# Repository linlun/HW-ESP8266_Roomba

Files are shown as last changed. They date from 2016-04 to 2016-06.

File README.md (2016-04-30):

# HW-ESP8266_Roomba
Kicad schematics of a generic ESP8266 board with interfaces for OLED-display, rotary encoder, Roomba and DC/DC

Make shore that the latest kicad libraries are installed at: C:\Program Files\KiCad\share\kicad
Download from https://github.com/KiCad/kicad-library adn extract in the folder above if not.

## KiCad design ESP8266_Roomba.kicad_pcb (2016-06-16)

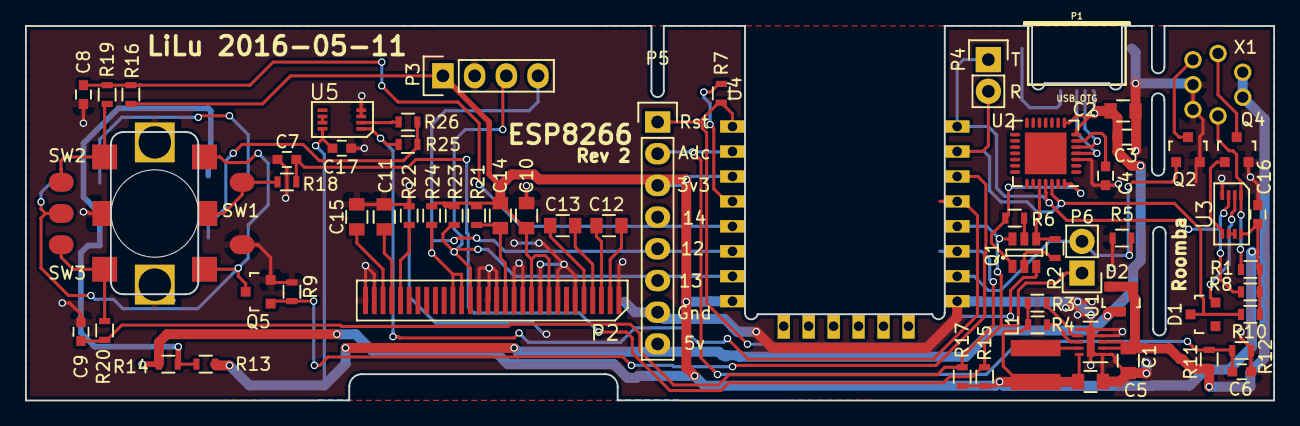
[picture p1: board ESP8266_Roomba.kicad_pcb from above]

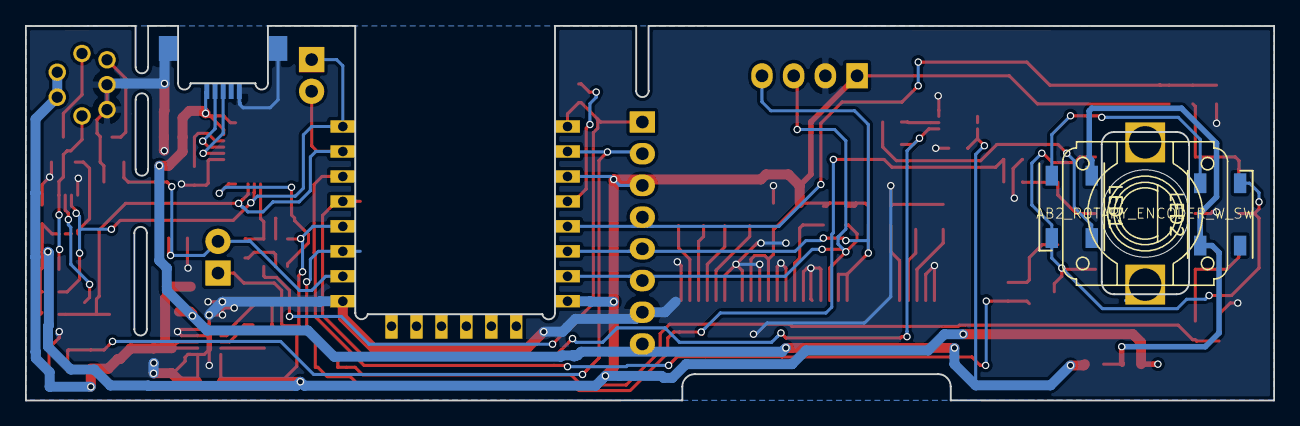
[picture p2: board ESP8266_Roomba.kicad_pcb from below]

Board: 2 copper layers, 100.0 x 30.0 mm, 68 parts (3 on the bottom side), 50 nets.

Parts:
C1, C11, C14, C15: 2u2; C_0805
C2, C10, C12, C13: 1u; C_0805
C3, C4, C6, C7, C8, C9, C16, C17: 100n; C_0603
C5: 22u; C_0805
D1, D2: MMBD717LT1G; SOT-23
L1: VLS4012ET-100M
LED1, LED2: WS2812B; LED_WS2812B-PLCC4
P1: USB_OTG; conn_usb_B_micro_smd-backside
P2: UG_62864
P3: CONN_01X04; Pin_Header_Straight_1x04
P4, P6: CONN_01X02; Pin_Header_Straight_1x02
P5: CONN_01X08; Pin_Header_Straight_1x08
Q1: DMC204010R; SOT-23-6
Q2, Q4, Q5: 2N7002; SOT-23
R1: 1M; R_0603
R2, R6, R7, R15, R16, R17, R21, R23, R24: 10k; R_0603
R3, R4, R5, R8, R9, R10: 100k; R_0603
R11: 470k; R_0603
R12: 18k; R_0603
R13, R14, R25, R26: 0R; R_0603
R18, R19, R20: 1k; R_0603
R22: 390k; R_0603
ROT_ENC1: AB2_ROTARY_ENCODER_W_SW; ROT_ENC_backside
SW1, SW2, SW3: SW_PUSH; switch3x6_smd
U1: TPS62177; DFN-10-1EP_2x3mm_Pitch0.5mm
U2: CP2102; QFN-28-1EP_5x5mm_Pitch0.5mm
U3, U5: 74LVC3G14; VSSOP-8
U4: ESP-12E; ESP-12E_SideMounted
X1: MINI_DIN_7; MiniDin-7

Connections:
+3V3: C5.1, C10.1, C14.1, C16.1, L1.2, P2.9, P2.11, P3.1, P5.3, R1.2, R3.1, R4.1, R8.1, R10.1, R14.1, R15.2, R16.2, R17.2, R21.2, R23.2, R24.2, U1.10, U3.8, U4.8
+12V: C1.1, D2.1, D2.2, R11.1, U1.2, U1.3, X1.1, X1.2
/5V: C2.1, C3.1, C17.1, D2.3, P1.1, P5.8, R13.2, U2.7, U2.8, U5.8
/ADC: C6.1, P5.2, R11.2, R12.1, U4.2
/DTR: Q1.1, R6.1, U2.28
/Enc_A: C9.1, R17.1, R20.2, U4.17
/Enc_B: C8.1, P5.4, R16.1, R19.2, U4.5
/LED: R25.2, U4.19, U5.1
/PowerOn: Q5.1, R9.2, U4.20
/RST: P5.1, Q1.3, R7.2, U4.1
/RTS: Q1.4, R2.1, U2.24
/RXD: D1.3, P4.2, R10.2, U2.26, U4.21
/Roomba_Wake: P6.2, Q2.1, R5.2, U4.16
/SCL: P2.18, P3.3, P5.6, R23.1, U4.7
/SDA: P2.19, P2.20, P3.4, P5.5, R24.1, U4.6
/Switch: C7.1, P6.1, Q1.6, R15.1, R18.2, U4.18
/TXD: P4.1, R8.2, U2.25, U3.3, U4.22
GND: C1.2, C2.2, C3.2, C4.2, C5.2, C6.2, C7.2, C8.2, C9.2, C11.2, C14.2, C15.2, C16.2, C17.2, P1.5, P1.6, P2.1, P2.6, P2.8, P2.10, P2.12, P2.13, P2.15, P2.16, P2.17, P2.29, P2.30, P3.2, P5.7, Q2.2, Q4.2, Q5.2, R5.1, R9.1, R12.2, R22.2, ROT_ENC1.6, ROT_ENC1.7, SW1.2, U1.1, U1.4, U1.5, U1.6, U1.11, U2.3, U3.4, U4.15, U5.3, U5.4, X1.6, X1.7
GNDPWR: LED1.3, LED2.3, Q5.3, ROT_ENC1.2, SW2.2, SW3.2
unnamed: C4.1, U2.6
unnamed: C10.2, P2.14, R21.1
unnamed: C11.1, P2.27
unnamed: C12.1, P2.2
unnamed: C12.2, P2.3
unnamed: C13.1, P2.4
unnamed: C13.2, P2.5
unnamed: C15.1, P2.28
unnamed: D1.2, U3.2
unnamed: L1.1, U1.9
unnamed: LED1.1, LED2.1, R13.1, R14.2
unnamed: LED1.2, LED2.4
unnamed: LED1.4, R25.1, R26.1
unnamed: P1.2, U2.5
unnamed: P1.3, U2.4
unnamed: P2.26, R22.1
unnamed: Q1.2, R2.2
unnamed: Q1.5, R6.2
unnamed: Q2.3, X1.5
unnamed: Q4.1, U3.5
unnamed: Q4.3, X1.3
unnamed: R1.1, U3.1, X1.4
unnamed: R3.2, U1.7
unnamed: R4.2, U1.8
unnamed: R7.1, U4.4
unnamed: R18.1, ROT_ENC1.4, SW1.1
unnamed: R19.1, ROT_ENC1.3, SW2.1
unnamed: R20.1, ROT_ENC1.1, SW3.1
unnamed: R26.2, U5.2
unnamed: U3.6, U3.7
unnamed: U5.6, U5.7

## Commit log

2016-04-30 Started project
    [ESP8266_Roomba.kicad_pcb, ESP8266_Roomba.sch]
2016-04-30 more components added to schematic
    [ESP8266_Roomba.sch]
2016-05-02 Added alot of footprints
    [ESP8266_Roomba.kicad_pcb, ESP8266_Roomba.sch]
2016-05-03 all footprints added
    [ESP8266_Roomba.kicad_pcb, ESP8266_Roomba.sch]
2016-05-03 some layout done
    [ESP8266_Roomba.kicad_pcb, ESP8266_Roomba.sch]
2016-05-09 more layout done
    [ESP8266_Roomba.kicad_pcb, ESP8266_Roomba.sch]
2016-05-10 layout done
    [ESP8266_Roomba.kicad_pcb, ESP8266_Roomba.sch]
2016-05-10 Finished, commit before creating a panel
    [ESP8266_Roomba.kicad_pcb, ESP8266_Roomba.sch]
2016-05-10 Added gerber output for panel with 3 boards
    [ESP8266_Roomba_panel_x_3-B.Cu.gbr, ESP8266_Roomba_panel_x_3-B.Mask.gbr, ESP8266_Roomba_panel_x_3-Edge.Cuts.gbr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]
2016-05-11 Revision 2 Fixed faulty footprint for diodes added partnumbers for more components calculated voltage devider for adc
    [ESP8266_Roomba.kicad_pcb, ESP8266_Roomba.sch]
2016-06-16 Added output BOM with some links to digikey
    [ESP8266_Roomba.csv, ESP8266_Roomba.kicad_pcb, ESP8266_Roomba.sch]
